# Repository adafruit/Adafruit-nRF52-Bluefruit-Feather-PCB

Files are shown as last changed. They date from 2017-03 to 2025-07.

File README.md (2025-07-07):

# Adafruit-nRF52-Bluefruit-Feather-PCB

PCB files for the Adafruit nRF52 Bluefruit Feather and the Adafruit
nRF52840 Feather Express.

Format is EagleCAD schematic and board layout.

These boards were designed before we spent effort on low power and are not intended for low power usage.

For more details, check out the product page at

    * https://www.adafruit.com/product/3406 (nRF52832)
    * https://www.adafruit.com/product/4062 (nRF52840)

Adafruit invests time and resources providing this open source design,
please support Adafruit and open-source hardware by purchasing
products from Adafruit!

Designed by Adafruit Industries.  
Creative Commons Attribution, Share-Alike license, check license.txt for more information
All text above must be included in any redistribution

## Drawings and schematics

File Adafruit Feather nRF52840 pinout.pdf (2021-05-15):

# Adafruit Feather nRF52840

## https://www.adafruit.com/product/4062

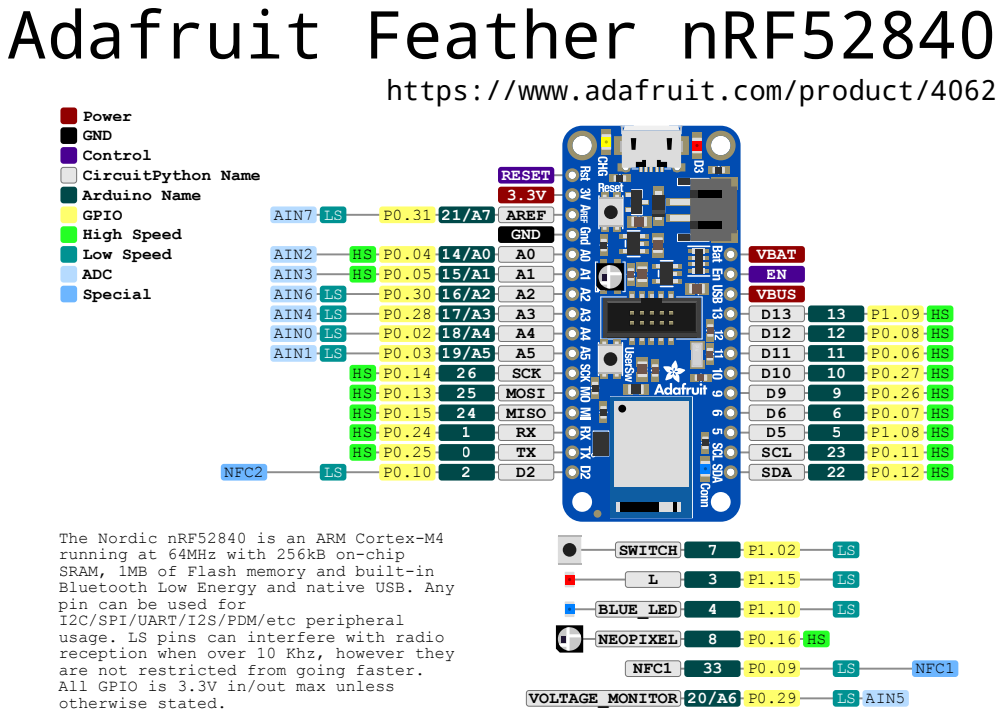
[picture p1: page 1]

The Nordic nRF52840 is an ARM Cortex-M4
running at 64MHz with 256kB on-chip
SRAM, 1MB of Flash memory and built-in
Bluetooth Low Energy and native USB. Any
pin can be used for
I2C/SPI/UART/I2S/PDM/etc peripheral
usage. LS pins can interfere with radio
reception when over 10 Khz, however they
are not restricted from going faster.
All GPIO is 3.3V in/out max unless
otherwise stated.

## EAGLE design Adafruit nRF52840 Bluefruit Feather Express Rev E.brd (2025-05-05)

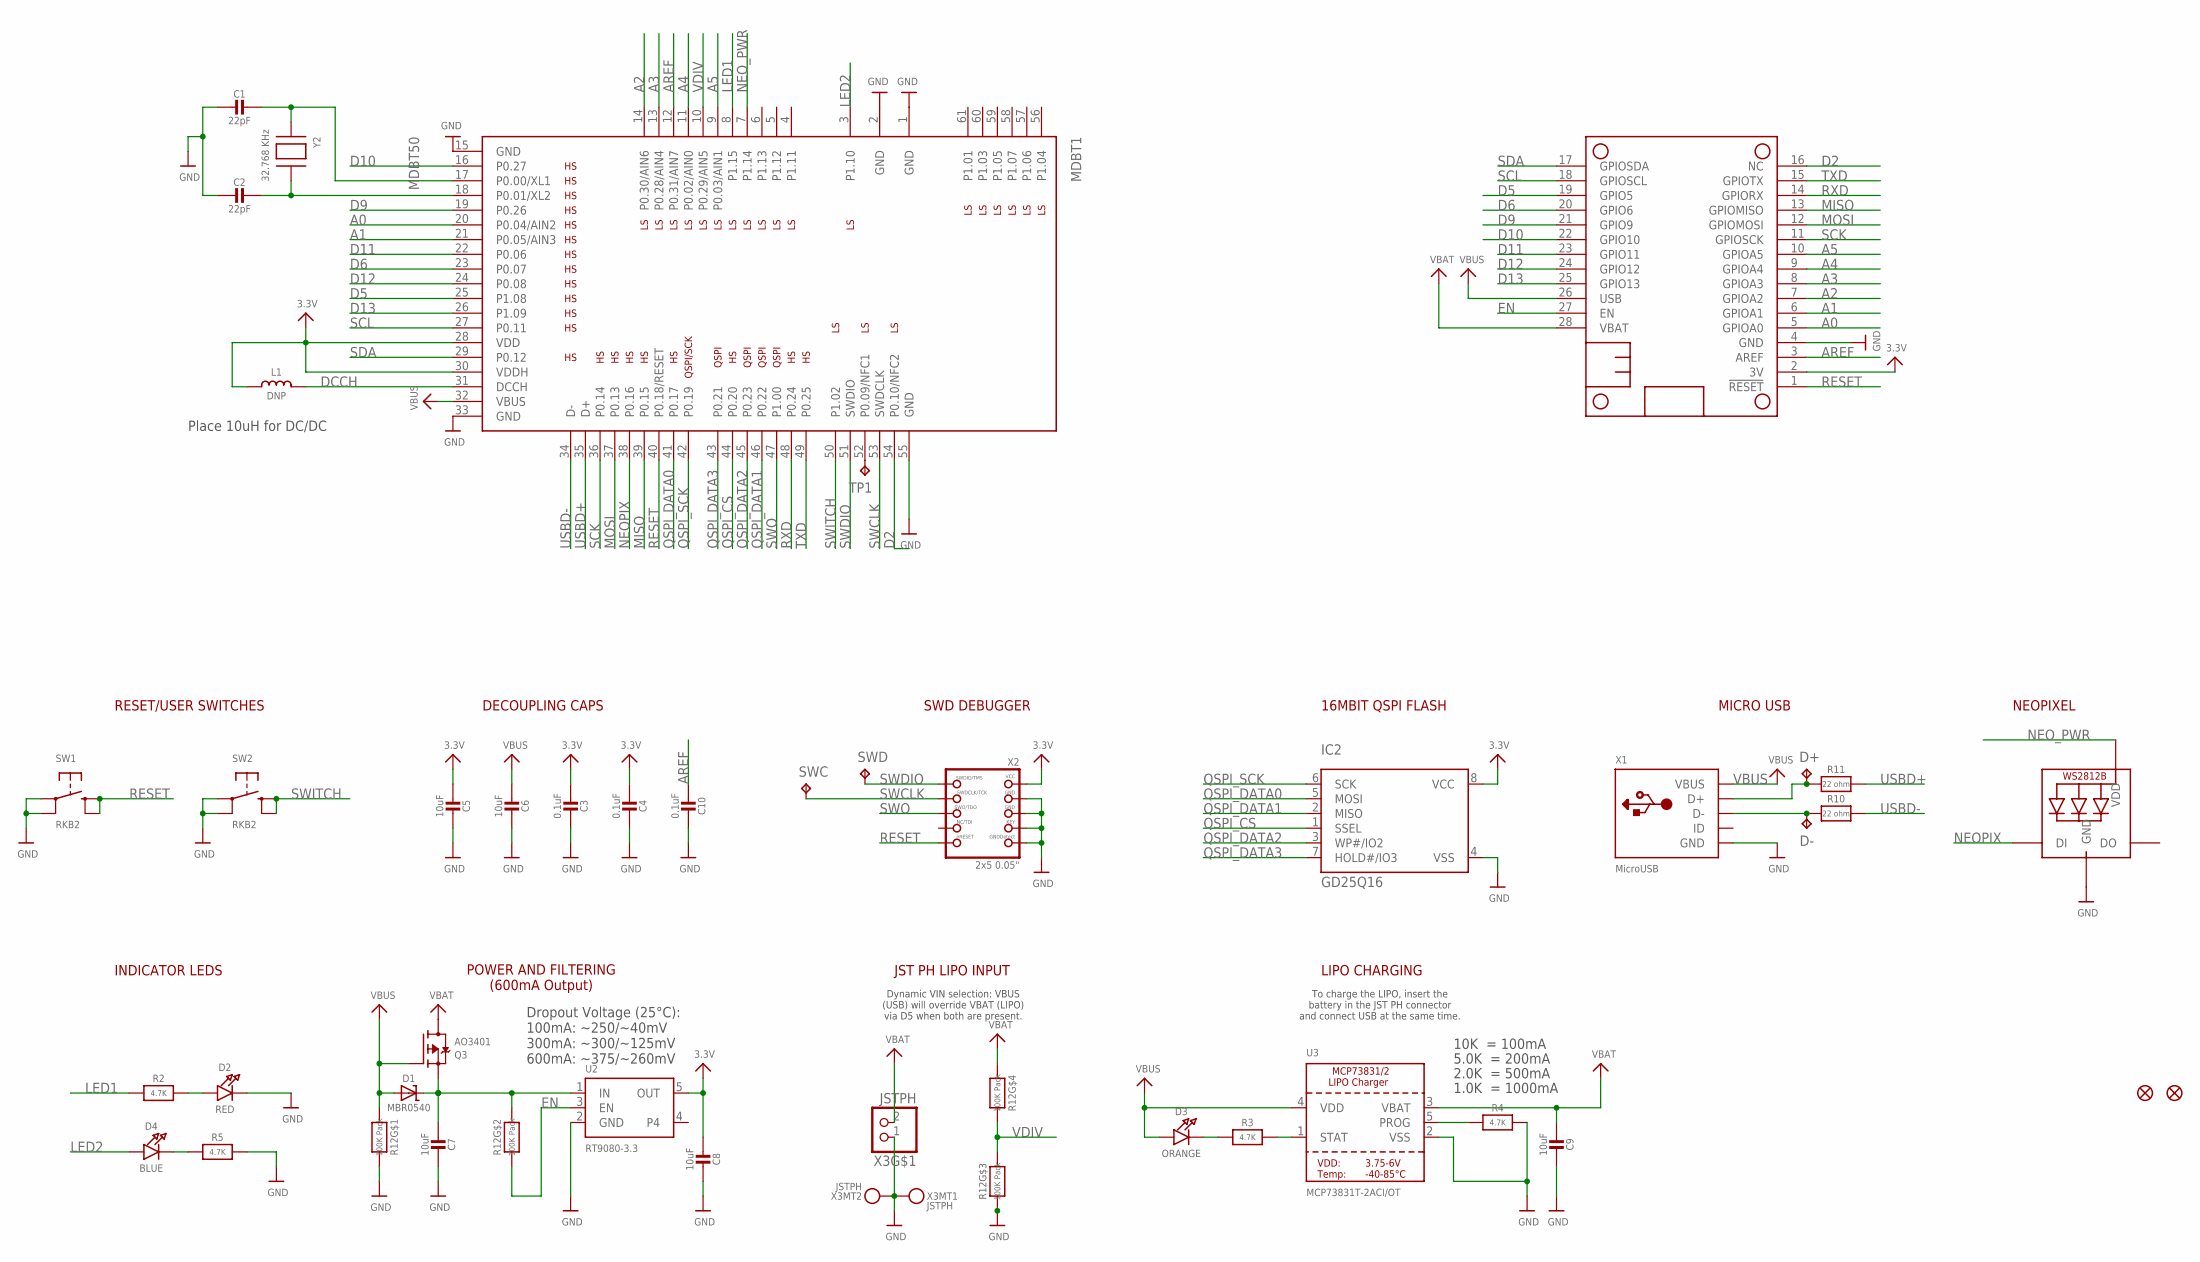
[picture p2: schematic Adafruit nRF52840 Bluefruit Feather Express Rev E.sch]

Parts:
C1, C2: 22pF; 0603-NO
C3, C4, C10: 0.1uF; 0603-NO
C5, C6, C7, C8, C9: 10uF; 0805-NO
D1: MBR0540; SOD-123
D2: RED; CHIPLED_0603_NOOUTLINE
D3: ORANGE; CHIPLED_0603_NOOUTLINE
D4: BLUE; CHIPLED_0603_NOOUTLINE
D+: TPTP10R; TP10R
D-: TPTP10R; TP10R
FID1, FID2: FIDUCIAL_1MM
IC2: GD25Q16; USON8
L1: DNP; _0805MP
LED1: WS2812B_3535FULL; LED3535_FULLPADS
MDBT1: MDBT50
MS1: FEATHERWING_NODIM
Q3: AO3401; SOT23-R
R2, R3, R4, R5: 4.7K; 0603-NO
R10, R11: 22 ohm; _0603MP
R12: 100K Pack; RESPACK_4X0603
SW1, SW2: RKB2; BTN_RKB2_4.6X2.8
SWC: TPTP12R; TP12R
SWD: TPTP12R; TP12R
TP1: TPTP10R; TP10R
U2: RT9080-3.3; SOT23-5; JLC_ROTATION 0
U3: MCP73831T-2ACI/OT; SOT23-5
X1: MicroUSB; 4UCONN_20329_V2
X2: 2x5 0.05"; 2X05_1.27MM_BOX_POSTS
X3: JSTPH; JSTPH2_BATT
Y2: 32.768 KHz; XTAL3215

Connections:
3.3V: C3.2, C4.2, C5.2, C8.2, IC2.8 (VCC), L1.1, MDBT1.28 (VDD), MDBT1.30 (VDDH), MS1.2 (3V), U2.5 (OUT), X2.1 (VCC)
A0: MDBT1.20 (P0.04/AIN2), MS1.5 (GPIOA0)
A1: MDBT1.21 (P0.05/AIN3), MS1.6 (GPIOA1)
A2: MDBT1.14 (P0.30/AIN6), MS1.7 (GPIOA2)
A3: MDBT1.13 (P0.28/AIN4), MS1.8 (GPIOA3)
A4: MDBT1.11 (P0.02/AIN0), MS1.9 (GPIOA4)
A5: MDBT1.9 (P0.03/AIN1), MS1.10 (GPIOA5)
AREF: C10.2, MDBT1.12 (P0.31/AIN7), MS1.3 (AREF)
D2: MDBT1.54 (P0.10/NFC2), MS1.16 (NC)
D5: MDBT1.25 (P1.08), MS1.19 (GPIO5)
D6: MDBT1.23 (P0.07), MS1.20 (GPIO6)
D9: MDBT1.19 (P0.26), MS1.21 (GPIO9)
D10: MDBT1.16 (P0.27), MS1.22 (GPIO10)
D11: MDBT1.22 (P0.06), MS1.23 (GPIO11)
D12: MDBT1.24 (P0.08), MS1.24 (GPIO12)
D13: MDBT1.26 (P1.09), MS1.25 (GPIO13)
D+: D+.TP, R11.1, X1.D+
D-: D-.TP, R10.1, X1.D-
DCCH: L1.2, MDBT1.31 (DCCH)
EN: MS1.27 (EN), R12.2 (1), U2.3 (EN)
GND: C1.2, C2.2, C3.1, C4.1, C5.1, C6.1, C7.1, C8.1, C9.1, C10.1, D2.C, IC2.4 (VSS), LED1.4 (GND), MDBT1.1 (GND), MDBT1.2 (GND), MDBT1.15 (GND), MDBT1.33 (GND), MDBT1.55 (GND), MS1.4 (GND), R4.2, R5.2, R12.3 (1), R12.8 (2), SW1.A, SW1.A' (P1), SW2.A, SW2.A' (P1), U2.2 (GND), U3.2 (VSS), X1.BASE@1 (GND), X1.BASE@2 (GND), X1.GND, X1.SPRT@1 (GND), X1.SPRT@2 (GND), X1.SPRT@3 (GND), X1.SPRT@4 (GND), X2.3 (GND), X2.5 (GND), X2.7 (KEY), X2.9 (GNDDETECT), X3.1, X3.NC1, X3.NC2
LED1: MDBT1.8 (P1.15), R2.1
LED2: D4.A, MDBT1.3 (P1.10)
MISO: MDBT1.39 (P0.15), MS1.13 (GPIOMISO)
MOSI: MDBT1.37 (P0.13), MS1.12 (GPIOMOSI)
unnamed: D3.C, R3.1
unnamed: D2.A, R2.2
unnamed: C1.1, MDBT1.17 (P0.00/XL1), Y2.P$1
unnamed: C2.1, MDBT1.18 (P0.01/XL2), Y2.P$2
unnamed: R3.2, U3.1 (STAT)
unnamed: R4.1, U3.5 (PROG)
unnamed: D4.C, R5.1
NEOPIX: LED1.1 (DI), MDBT1.38 (P0.16)
NEO_PWR: LED1.2 (VDD), MDBT1.7 (P1.14)
NFC2: MDBT1.52 (P0.09/NFC1), TP1.TP
QSPI_CS: IC2.1 (SSEL), MDBT1.44 (P0.20)
QSPI_DATA0: IC2.5 (MOSI), MDBT1.41 (P0.17)
QSPI_DATA1: IC2.2 (MISO), MDBT1.46 (P0.22)
QSPI_DATA2: IC2.3 (WP#/IO2), MDBT1.45 (P0.23)
QSPI_DATA3: IC2.7 (HOLD#/IO3), MDBT1.43 (P0.21)
QSPI_SCK: IC2.6 (SCK), MDBT1.42 (P0.19)
RESET: MDBT1.40 (P0.18/RESET), MS1.1 (!RESET), SW1.B (S), SW1.B' (S1), X2.10 (NRESET)
RXD: MDBT1.48 (P0.24), MS1.14 (GPIORX)
SCK: MDBT1.36 (P0.14), MS1.11 (GPIOSCK)
SCL: MDBT1.27 (P0.11), MS1.18 (GPIOSCL)
SDA: MDBT1.29 (P0.12), MS1.17 (GPIOSDA)
SWCLK: MDBT1.53 (SWDCLK), SWC.TP, X2.4 (SWDCLK)
SWDIO: MDBT1.51 (SWDIO), SWD.TP, X2.2 (SWDIO)
SWITCH: MDBT1.50 (P1.02), SW2.B (S), SW2.B' (S1)
SWO: MDBT1.47 (P1.00), X2.6 (SWO)
TXD: MDBT1.49 (P0.25), MS1.15 (GPIOTX)
USBD+: MDBT1.35 (D+), R11.2
USBD-: MDBT1.34 (D-), R10.2
VBAT: C9.2, MS1.28 (VBAT), Q3.3 (D), R12.4 (1), U3.3 (VBAT), X3.2
VBUS: C6.2, D1.A, D3.A, MDBT1.32 (VBUS), MS1.26 (USB), Q3.1 (G), R12.1, U3.4 (VDD), X1.VBUS
VDIV: MDBT1.10 (P0.29/AIN5), R12.5 (2), R12.6 (2)
VHI: C7.2, D1.C, Q3.2 (S), R12.7 (2), U2.1 (IN)

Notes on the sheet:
10K = 100mA
5.0K = 200mA
2.0K = 500mA
1.0K = 1000mA
LIPO CHARGING
To charge the LIPO, insert the battery in the JST PH connector and connect USB at the same time.
POWER AND FILTERING (600mA Output)
JST PH LIPO INPUT
Dynamic VIN selection: VBUS (USB) will override VBAT (LIPO) via D5 when both are present.
Dropout Voltage (25°C): 100mA: ~250/~40mV 300mA: ~300/~125mV 600mA: ~375/~260mV
INDICATOR LEDS
RESET/USER SWITCHES
DECOUPLING CAPS
SWD DEBUGGER
16MBIT QSPI FLASH
MICRO USB
NEOPIXEL
Place 10uH for DC/DC

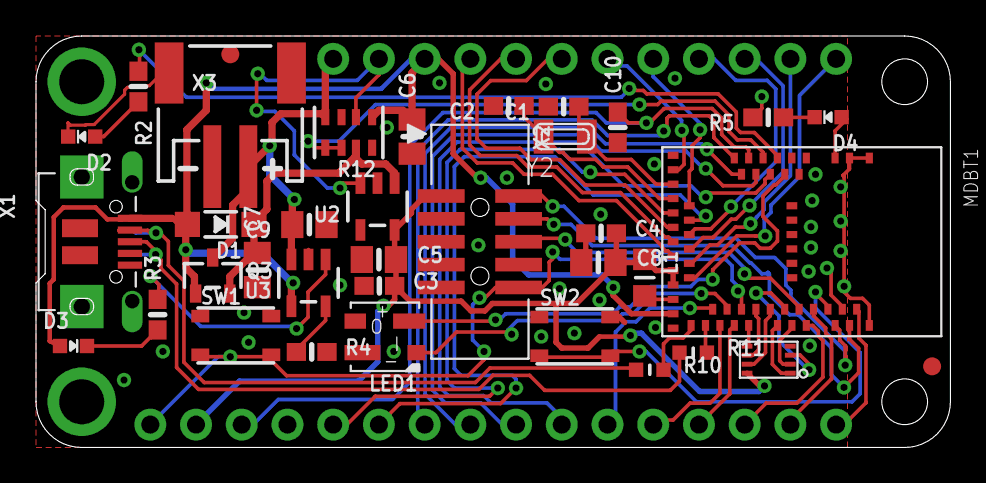
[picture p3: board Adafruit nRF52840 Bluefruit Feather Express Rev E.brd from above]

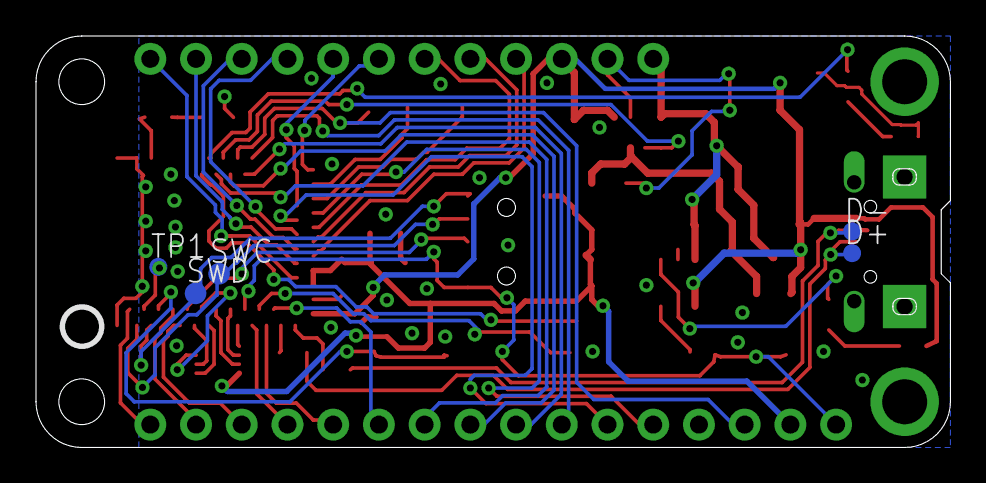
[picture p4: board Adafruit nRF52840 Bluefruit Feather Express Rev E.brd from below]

Board: 2 copper layers, 50.8 x 22.9 mm, 45 parts (7 on the bottom side), 57 nets.

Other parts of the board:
U$10: PCBFEAT-REV-056
U$12: NRF52840_BOT
U$14: NRF52840_TOP

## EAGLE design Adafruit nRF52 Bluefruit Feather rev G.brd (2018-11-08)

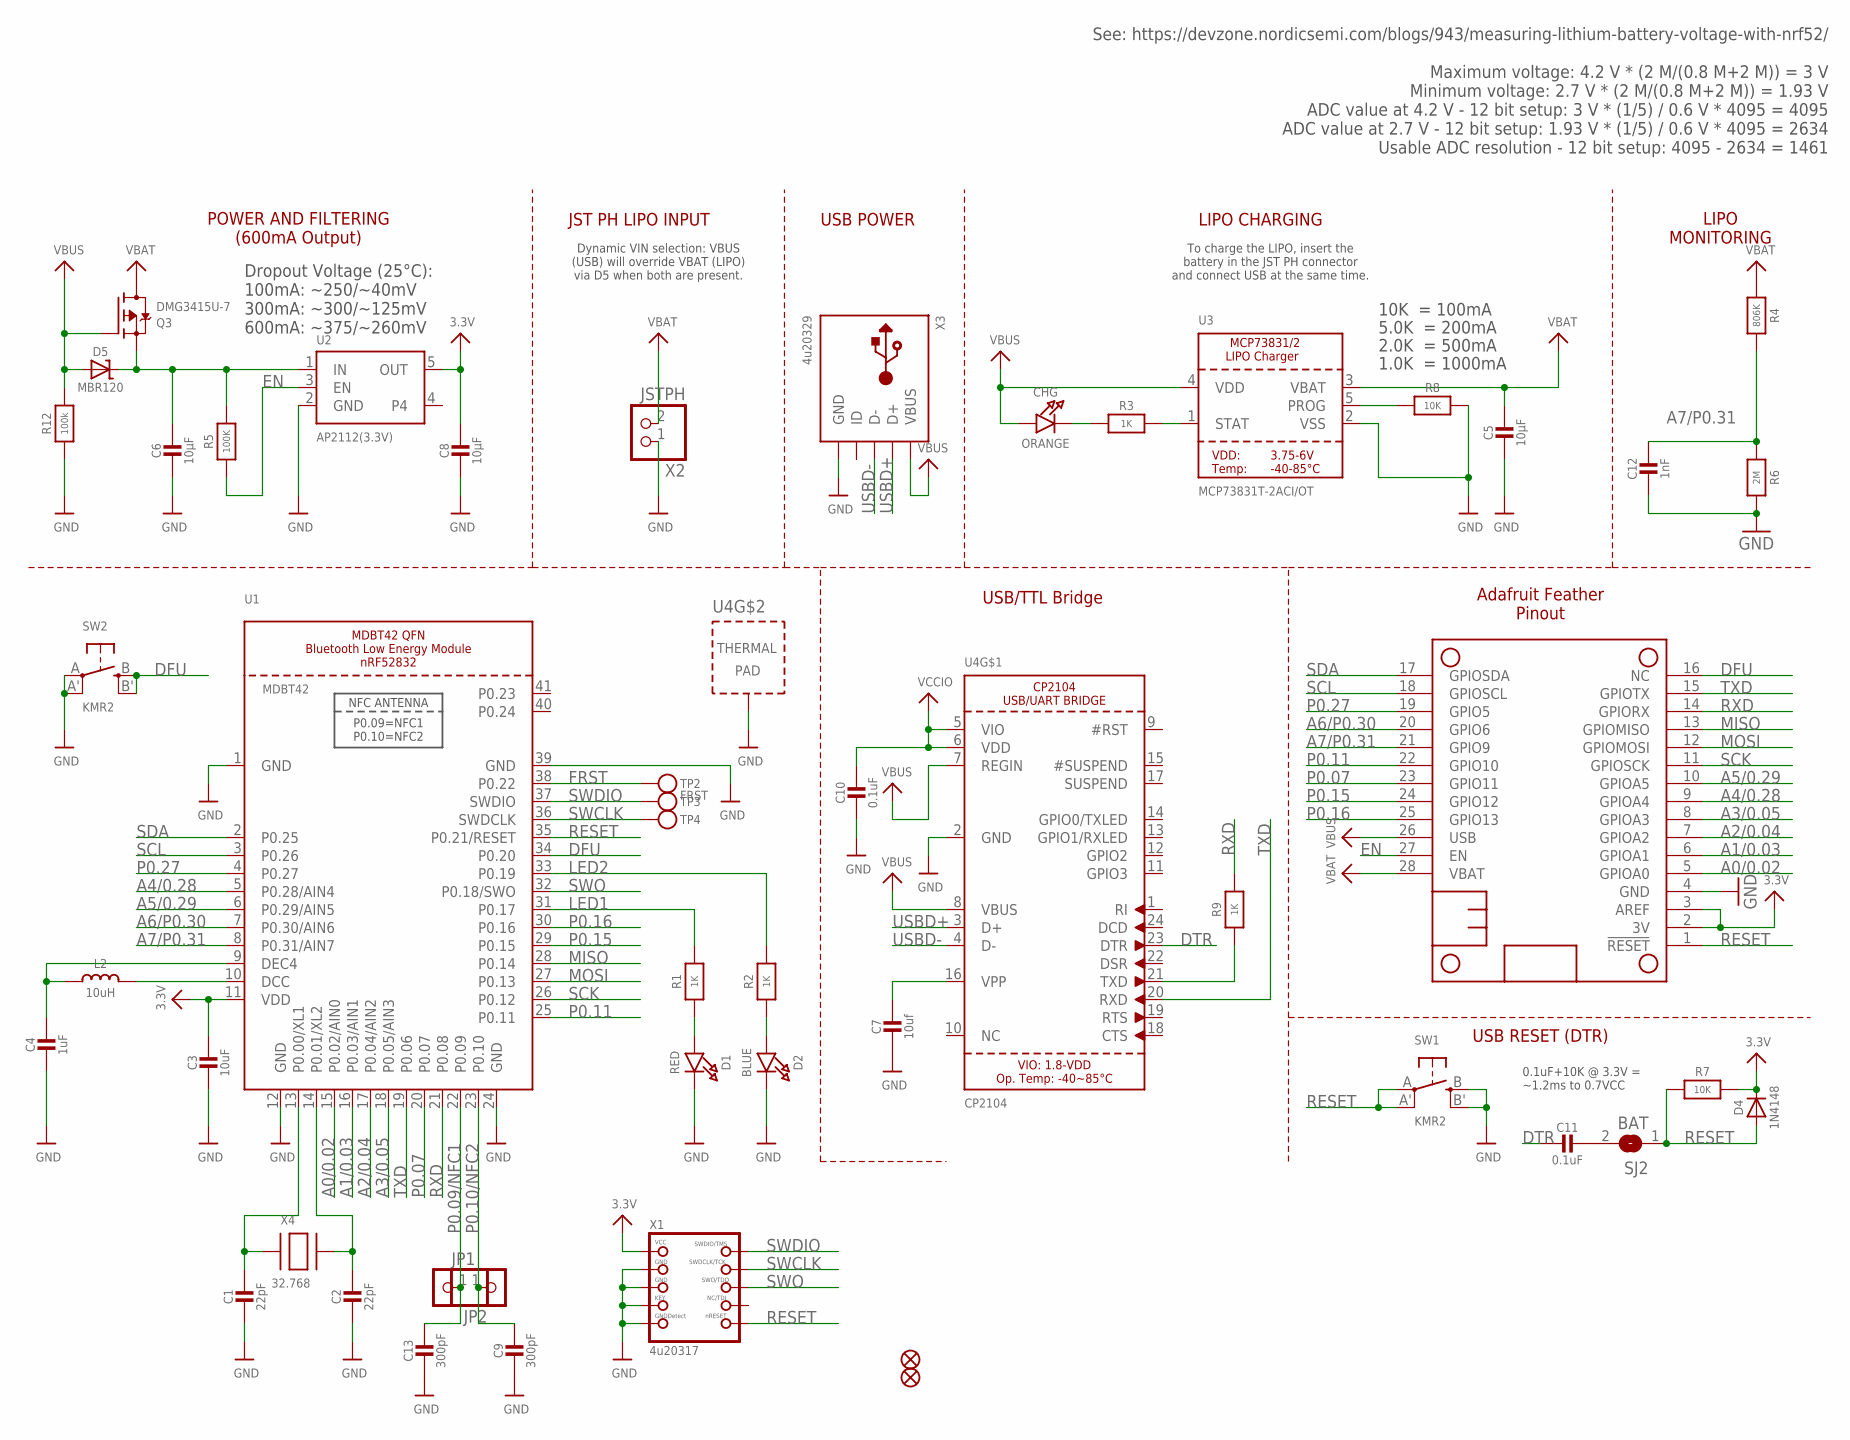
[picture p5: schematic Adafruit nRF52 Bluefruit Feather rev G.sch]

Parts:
C1, C2: 22pF; 0603-NO
C3: 10uF; 0805-NO
C4: 1uF; 0603-NO
C5, C6, C8: 10µF; 0805-NO
C7: 10uf; 0805-NO
C9, C13: 300pF; _0603MP
C10, C11: 0.1uF; 0603-NO
C12: 1nF; 0603-NO
CHG: ORANGE; CHIPLED_0805_NOOUTLINE
D1: RED; CHIPLED_0805_NOOUTLINE
D2: BLUE; CHIPLED_0805_NOOUTLINE
D4: 1N4148; SOD-323
D5: MBR120; SOD-123
FID1, FID3: FIDUCIAL_1MM
JP1, JP2: HEADER-1X12MM; 1X01_2MM
L2: 10uH; 0805-NO
MS1: FEATHERWING_NODIM
Q3: DMG3415U-7; SOT23-R
R1, R2, R3, R9: 1K; 0603-NO
R4: 806K; 0603-NO
R5: 100K; 0603-NO
R6: 2M; 0603-NO
R7, R8: 10K; 0603-NO
R12: 100k; 0603-NO
SJ2: BAT; SOLDERJUMPER_CLOSEDWIRE
SW1, SW2: KMR2; BTN_KMR2_4.6X2.8
TP2: FRST; PAD-1.5X2.0
TP3, TP4: TESTPOINTROUND2MM; TESTPOINT_ROUND_2MM
U1: MDBT42; BLE_MODULE_RAYTAC_MDBT42
U2: AP2112(3.3V); SOT23-5
U3: MCP73831T-2ACI/OT; SOT23-5
U4: CP2104; QFN24_4MM_SMSC
X1: 4u20317; 2X05_1.27MM_BOX_POSTS
X2: JSTPH; JSTPH2
X3: 4u20329; 4UCONN_20329_V2
X4: 32.768; XTAL3215

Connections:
3.3V: C3.1, C8.1, D4.C, MS1.2 (3V), MS1.3 (AREF), R7.2, U1.11 (VDD), U2.5 (OUT), X1.1 (VCC)
A0/0.02: MS1.5 (GPIOA0), U1.15 (P0.02/AIN0)
A1/0.03: MS1.6 (GPIOA1), U1.16 (P0.03/AIN1)
A2/0.04: MS1.7 (GPIOA2), U1.17 (P0.04/AIN2)
A3/0.05: MS1.8 (GPIOA3), U1.18 (P0.05/AIN3)
A4/0.28: MS1.9 (GPIOA4), U1.5 (P0.28/AIN4)
A5/0.29: MS1.10 (GPIOA5), U1.6 (P0.29/AIN5)
A6/P0.30: MS1.20 (GPIO6), U1.7 (P0.30/AIN6)
A7/P0.31: C12.1, MS1.21 (GPIO9), R4.2, R6.1, U1.8 (P0.31/AIN7)
DFU: MS1.16 (NC), SW2.B (S), SW2.B' (S1), U1.34 (P0.20)
DTR: C11.2, U4.23 (DTR)
EN: MS1.27 (EN), R5.1, U2.3 (EN)
FRST: TP2.P$1, U1.38 (P0.22)
GND: C1.2, C2.2, C3.2, C4.2, C5.2, C6.2, C7.2, C8.2, C9.2, C10.2, C12.2, C13.2, D1.C, D2.C, MS1.4 (GND), R6.2, R8.2, R12.1, SW1.B (S), SW1.B' (S1), SW2.A, SW2.A' (P1), U1.1 (GND), U1.12 (GND), U1.24 (GND), U1.39 (GND), U2.2 (GND), U3.2 (VSS), U4.2 (GND), U4.THERM (TP), X1.3 (GND), X1.5 (GND), X1.7 (KEY), X1.9 (GNDDETECT), X2.1, X3.BASE@1 (GND), X3.BASE@2 (GND), X3.GND, X3.SPRT@1 (GND), X3.SPRT@2 (GND), X3.SPRT@3 (GND), X3.SPRT@4 (GND)
LED1: R1.2, U1.31 (P0.17)
LED2: R2.2, U1.33 (P0.19)
MISO: MS1.13 (GPIOMISO), U1.28 (P0.14)
MOSI: MS1.12 (GPIOMOSI), U1.27 (P0.13)
unnamed: C1.1, U1.13 (P0.00/XL1), X4.P$1
unnamed: C2.1, U1.14 (P0.01/XL2), X4.P$2
unnamed: L2.2, U1.10 (DCC)
unnamed: CHG.C, R3.1
unnamed: D1.A, R1.1
unnamed: D2.A, R2.1
unnamed: C4.1, L2.1, U1.9 (DEC4)
unnamed: R3.2, U3.1 (STAT)
unnamed: R8.1, U3.5 (PROG)
unnamed: R9.1, U4.21 (TXD)
unnamed: C11.1, SJ2.2
unnamed: C7.1, U4.16 (VPP)
P0.07: MS1.23 (GPIO11), U1.20 (P0.07)
P0.09/NFC1: C13.1, JP2.1, U1.22 (P0.09)
P0.10/NFC2: C9.1, JP1.1, U1.23 (P0.10)
P0.11: MS1.22 (GPIO10), U1.25 (P0.11)
P0.15: MS1.24 (GPIO12), U1.29 (P0.15)
P0.16: MS1.25 (GPIO13), U1.30 (P0.16)
P0.27: MS1.19 (GPIO5), U1.4 (P0.27)
RESET: D4.A, MS1.1 (!RESET), R7.1, SJ2.1, SW1.A, SW1.A' (P1), U1.35 (P0.21/RESET), X1.10 (NRESET)
RXD: MS1.14 (GPIORX), R9.2, U1.21 (P0.08)
SCK: MS1.11 (GPIOSCK), U1.26 (P0.12)
SCL: MS1.18 (GPIOSCL), U1.3 (P0.26)
SDA: MS1.17 (GPIOSDA), U1.2 (P0.25)
SWCLK: TP4.P$1, U1.36 (SWDCLK), X1.4 (SWDCLK)
SWDIO: TP3.P$1, U1.37 (SWDIO), X1.2 (SWDIO)
SWO: U1.32 (P0.18/SWO), X1.6 (SWO)
TXD: MS1.15 (GPIOTX), U1.19 (P0.06), U4.20 (RXD)
USBD+: U4.3 (D+), X3.D+
USBD-: U4.4 (D-), X3.D-
VBAT: C5.1, MS1.28 (VBAT), Q3.3 (D), R4.1, U3.3 (VBAT), X2.2
VBUS: CHG.A, D5.A, MS1.26 (USB), Q3.1 (G), R12.2, U3.4 (VDD), U4.7 (REGIN), U4.8 (VBUS), X3.VBUS
VCCIO: C10.1, U4.5 (VIO), U4.6 (VDD)
VIN: C6.1, D5.C, Q3.2 (S), R5.2, U2.1 (IN)

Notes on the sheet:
10K = 100mA
5.0K = 200mA
2.0K = 500mA
1.0K = 1000mA
LIPO CHARGING
LIPO MONITORING
To charge the LIPO, insert the battery in the JST PH connector and connect USB at the same time.
POWER AND FILTERING (600mA Output)
JST PH LIPO INPUT
Dynamic VIN selection: VBUS (USB) will override VBAT (LIPO) via D5 when both are present.
Dropout Voltage (25°C): 100mA: ~250/~40mV 300mA: ~300/~125mV 600mA: ~375/~260mV
USB POWER
USB/TTL Bridge
Adafruit Feather Pinout
See: https://devzone.nordicsemi.com/blogs/943/measuring-lithium-battery-voltage-with-nrf52/ Maximum voltage: 4.2 V * (2 M/(0.8 M+2 M)) = 3 V Minimum voltage: 2.7 V * (2 M/(0.8 M+2 M)) = 1.93 V ADC value at 4.2 V - 12 bit setup: 3 V * (1/5) / 0.6 V * 4095 = 4095 ADC value at 2.7 V - 12 bit setup: 1.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
USB RESET (DTR)
0.1uF+10K @ 3.3V = ~1.2ms to 0.7VCC

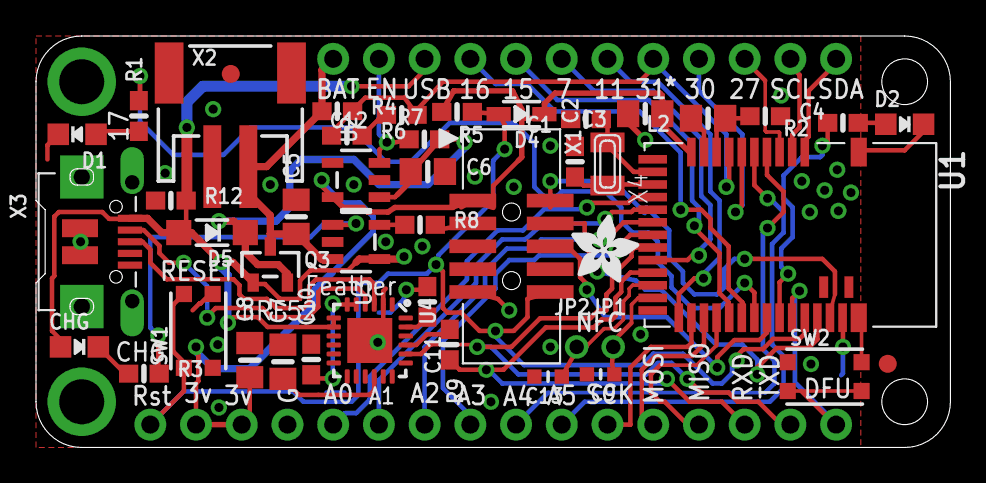
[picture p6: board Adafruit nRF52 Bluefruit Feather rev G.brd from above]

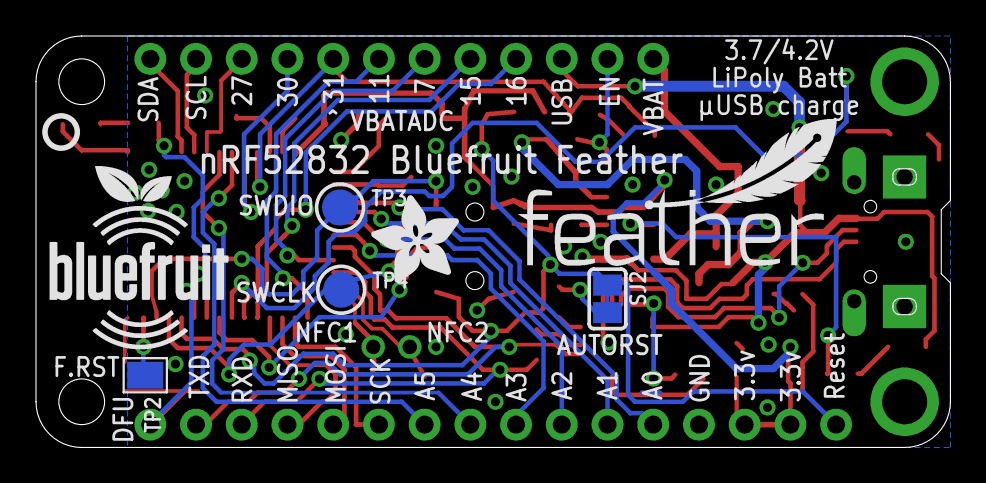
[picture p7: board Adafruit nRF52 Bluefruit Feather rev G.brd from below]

Board: 2 copper layers, 50.8 x 22.9 mm, 54 parts (8 on the bottom side), 52 nets.

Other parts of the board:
U$17: PCBFEAT-REV-040
U$45: BLUEFRUITLOGO_100MM
U$46: FEATHERLOGO_MED
U$47: ADAFRUIT_5MM
U$49: ADAFRUIT_3.5MM

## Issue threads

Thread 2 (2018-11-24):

No space for screw heads on one side

jps2000, 2018-11-24:
There is almost no space for screws on the MDBT42 side. in particular the LED is endangered.
Pls improve  in the next layout if possible. Find attached my suggestions.
[adafruit feather nrf52 revG_JPS.zip](https://github.com/adafruit/Adafruit-nRF52-Bluefruit-Feather-PCB/files/2612101/adafruit.feather.nrf52.revG_JPS.zip)

ladyada, 2018-11-25:
thanks for the note! these are already in production, and we're unlikely to do any revisions soon - but when we do we'll move the LED as well :)

jps2000, 2018-11-26:
Thanks.
Of course I understand that.
Lets follow the basic wisdom "never change a running system"

ladyada, 2018-11-26:
indeed :)

Closed 2018-11-25.

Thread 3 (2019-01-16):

nRF52840 question: why is the AP2112 present on the board?

lbdroid, 2019-01-16:
The specifications for the nRF52840 include DCDC and LDO power regulators onboard capable of being supplied by any voltage from 1.7 to 5.5, including the ability to drive external 3.3v components (specifically, the multi-color LED and the external flash). The AP2112 has a quiescent current of 55-80 uA, which appears to be an unnecessary waste since the datasheet for the nRF52840 suggest that it can consume as little as 1 uA while being supplied by 5V.

It seems to me that the circuit would be simplified and efficiency improved by removing the AP2112, and instead of tying the nRF52840's VDDH to VDD, connect VDDH to the cathode of D1.

ladyada, 2019-01-16:
we need 300mA minimum for accessories, whats the spec of the nRF52840 LDO?

lbdroid, 2019-01-16:
Ah, ok. Then it makes sense since the nRF is maximum 25 mA. I suppose then that it would be nice to be able to operate without the AP2112 when external accessories are not required.

Closed 2019-01-16.

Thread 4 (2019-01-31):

Low power consumption on nrf52840

jps2000, 2019-01-31:
Just looked over the schematic of rev D
To achieve lowest Vbat and OFF current pls consider following changes:

1) Make the VDIV divider same as in the nrf52832 board (high ohmic  + add capacitor!)
It takes now 20uA

2)EN Pullup use 1M or even more to  allow low power shutdown
 (EN pulldown is 3M , >1.5V is required
It takes  now 40 uA

3)  Replace D1 MBR120 by a  Si diode which has less leakage current
It takes now 25uA to 200uA
Thanks

ladyada, 2019-01-31:
awesome, thanks!
1. please try the vdiv with higher values, let us know if they work!
2. please try various pullup values, we found 100k works best
3. please recommend a same-package diode with 0.2V forward voltage and low leakage

jps2000, 2019-02-05:
ad 1.
The vdiv with higher values is indeed present in the 52832 board. however such  high impedance voltage dividers need capacitor to gnd for proper adc operation ( done in the 52832 board)
--> suggest to add capacitor 1..10nF  in next  52840 layout and change voltage divider to 2M + 2M.
ad 2.
2M2 also works fine. The penalty is that inadvertently touching the pins with fingers can lead to  a short shut down.  So this may be a problem  with modules lying around on the table. 220k or 470k may be a compromise.
ad 3.
I see no need for a 0.2V voltage drop as  the diode just supplies the 3V3 low drop voltage regulator.
So I actually use just a 1N4148 instead of the Schottky. However current consumption is then limited to 150mA. It is likely less robust to shorts.
There are also some more capable SOD123  Si diodes but they are somehow rare.

With above changes I  achieved <10uA  (~7uA) off current (with EN = LOW).
Maybe helpful for some users.

jps2000, 2019-02-05:
There are these SL1 A... M types from Diotec for example they claim <1uA@ 25° leakage
may be considered.....

jps2000, 2019-04-04:
seems to be actual
https://forums.adafruit.com/posting.php?mode=reply&f=57&t=146360

Eric-FR, 2020-04-21:
(2): I made a current measurement on my Feather nrf52840 with an external power supply of 3.6 V on the BAT pin. I found 100 µA and I don't understand (although not critical for my project). 100 kOhm on the ENable pin: 36 µA. Battery voltage divider, 200 kOhm: 18 µA.

(4): There is a neopixel LED, ref.: WS2812B. The Quiescent Current is of 0,5 mA when the LED is off.

[https://lowpowerlab.com/forum/general-topics/ws2812b-rgb-led-measurements/](url).

This should explain why I get a current of 600 µA at rest with a loopless sketch.

[https://github.com/MacGyverNL/Adafruit_nRF52_Arduino/tree/LowPower_examples/libraries/Bluefruit52Lib/examples/LowPower/Blink_loopless](url)

One should note that on the ItsyBitsy, there is DotStar LED with ref. APA102-2020. It is also having a gargantuan Quiescent Current of 0,8 mA.

[https://memcpy.io/apa102-led-current-usage.html](url)

The latter may be easier to unsolder, considering the SWD connector position on the Feather one. But, overall, it seems to be a big drawback to low power management of booth boards. Again, the Feather nfr52832 would be more suitable.

mhx, 2020-04-29:
FWIW, I can confirm that...
- ripping out the neopixel
- replacing the AP2112 with an AP7354D
- replacing the MBR120 with an STTH1R02ZF
...brings the total current draw down to 20µA. 18µA are still wasted for the VDIV (no need to verify that and I'm not particularly keen on replacing the 4x100k array), the remainder is likely 1.5µA for the Raytac module and 0.5µA reverse leakage from the STTH1R02ZF.

mhx, 2020-04-29:
> true it does not need to be a schottky since, but we need to supply up to 500mA peak to the regulator, can you suggest a diode that can do that? (in the same package)

The STTH1R02ZF can handle up to 1A with a max. 0.5µA reverse leakage.
The AP7354D seems to be fully compatible with the AP2112.

ladyada, 2020-04-29:
@mhx thank you for being so helpful :) we'll check those parts out!

ladyada, 2020-04-29:
@mhx  STTH1R02ZF has very high Vf, 0.75 - can you try MBR054?
https://www.digikey.com/product-detail/en/on-semiconductor/MBR0540T1G/MBR0540T1GOSTR-ND/918576

mhx, 2020-04-29:
WRT the voltage divider, there's a [full article from Nordic Semi](https://devzone.nordicsemi.com/nordic/nordic-blog/b/blog/posts/measuring-lithium-battery-voltage-with-nrf52) on how to design a high resistance divider for the nRF52. It's really straightforward and the only additional component needed is a capacitor as already mentioned by @jps2000.

mhx, 2020-04-29:
> @mhx STTH1R02ZF has very high Vf, 0.75 - can you try MBR054?
> https://www.digikey.com/product-detail/en/on-semiconductor/MBR0540T1G/MBR0540T1GOSTR-ND/918576
I don't have one of those lying around, but I can put a handful on my next digikey order and give it a try.
Why are you concerned about the higher voltage drop? There should be plenty of headroom going from 5 to 3.3V.

ladyada, 2020-04-29:
USB can droop down to 4.25V when current spikes - at 1A Vf 0.9V and we also need some headroom for the LDO at spikes

mhx, 2020-04-29:
> The AP7354D seems to be fully compatible with the AP2112.
Actually, it's not — just had another look at the datasheet — it'll only output up to 150mA. :/

glenne, 2021-02-07:
I see this thread is over a year old.  Any chance an updated rev of the nrf52840 will have the lower current mods?

glenne, 2021-02-20:
@ladyada [I tried the mods](https://forums.adafruit.com/viewtopic.php?f=57&t=164751#p855542) with the AP7354D and MBR0501T1G and got down to 29 uA.  150mA is plenty for my application.  Would really be nice if the production board didn't need hardware mods to be a 'low energy' BLE peripheral.

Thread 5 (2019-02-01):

Schematic for nrf52840 (on website) has an typo/error

jpconstantineau, 2019-02-01:
Comment on dynamic VIN selection pints to D5.  I think you mean D1.

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

awneil, 2020-11-12:
indeed - there is no D5.

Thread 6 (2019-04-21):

No polarity indicated for battery connector on silkscreen

dsiee, 2019-04-21:
A small + indicating battery polarity would be beneficial on the silkscreen. There is room for this on the back either side of the voltage indication "3.7/4.2V". Particularly important with the now large supply of PH2.0 connector batteries used in mini-quads with the opposite polarity coupled with the minimal reverse polarity handling of the board.

int3ll3ct, 2019-11-09:
I concur, I just smoked a board, a 5-pin component melted on the board, I incorrectly asumed that the battery industry was standardizing around this style plug AND polarity...

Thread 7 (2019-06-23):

Neopixel problems when USB is above 5V (nrf52840)

dsteinman, 2019-06-23:
Although a computer USB connection is usually around 5.0V, some USB chargers put out slightly more than that.  I have 3 on hand at 5.11V, 5.15V, and 5.26V.  All three create problems which in my case, manifest as the first Neopixel on a WS2812 strip flickering green (I am using the Adafruit neopixel library).

The 5.15V one (an iPad Charger) works best of the three, the neopixel still occasionally flickers green, but quite a lot less.  The other chargers are a Samsung phone charger, and a charger that came with a Raspberry Pi 3.

The problems persist regardless of whether the battery is connected.

I noticed in the schematic, that the VBUS line is wired to the nrf pin 32.  I'd need to look into the NRF documentation a bit further to determine what the threshold is for this pin, but I suspect that it may be the cause of my problems.

Would wiring the VHI line to pin 32 be a potential fix?  It's after the D1 diode, so the voltage would be a tad lower, and may resolve the issue.  (I'm probably going to try this out and see the results).

ladyada, 2019-06-23:
hiya you probably need a level shifter - see https://learn.adafruit.com/adafruit-neopixel-uberguide/

dsteinman, 2019-06-23:
I should have clarified, I am not using the 5V line to power the neopixels.  It is a 24 pixel strip connected to the 3.3V line from the feather board.  So it's already at 3.3V (althought it tests slightly lower ~3.26V).  Everything works good until a USB charger sends >5V.

ladyada, 2019-06-23:
hiya we'd need to see some scope traces of the power/data to see whats going on

Closed 2019-06-23.

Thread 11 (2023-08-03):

Please provide PDF files of schematic and gerbers of layout

smahnken, 2023-08-03:
Please post PDF files of the schematic and gerber files for the board layout so that we can see the design without having to install Eagle.

Thank you.

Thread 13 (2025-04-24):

Higher power consumption on nrf52840 Rev E boards

donmsmall, 2025-04-24:
Recent [nrf52840](https://www.adafruit.com/product/4062) boards I've bought are now showing an updated PCB version E.  I have not been able to find any documentation concerning changes from Rev D to Rev E. Last revision history on the product page is dated Nov. 2019.   The nrf52840 learning guide contains a reference to [NEOPIXEL_POWER](https://learn.adafruit.com/introducing-the-adafruit-nrf52840-feather?view=all#circuitpython-pins-and-modules) in the CircuitPython section.  I've also found a reference in the Arduino variant.cpp file to a NEO Pixel power pin.  Sounds promissing that we might not need to remove the NEO Pixel LED from the board to get lowerr current.

variant.h

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

variant.cpp

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

I've been using the Rev D board and removing the NEO Pixel LED to get an idle current of 63uA, which is great for my project.

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

But now the Rev E board with NEO Pixel still on the board shows idle current of 1.1mA.

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

Do I have the logic backwards to disable the NEO Pixel?  I wrote some test code to prove to myself that setting PIN_NEOPIXEL_POWER high does enable the NEO Pixel and setting PIN_NEOPIXEL_POWER low turns it off.  I've removed the NEO Pixel LED on one board and still get 1.1mA of idle current.

I've not been able to find a schematic for Rev E, so no idea how to get the current down similar to the discussion in [Issue #4 ](https://github.com/adafruit/Adafruit-nRF52-Bluefruit-Feather-PCB/issues/4).

Rev E with no mods is 1.1mA and Rev D with no mods is around .5mA.

Any help on power reduction would be appreciated.  Links to schematics would be helpful but I understand how those are probably just copied and your designs stolen so now you have to keep those under lock and key.

ladyada, 2025-05-02:
yes these boards were designed before we spent effort on low power (they were never intended for low power usage :/
@BlitzCityDIY plz post the rev E files at your convenience

BlitzCityDIY, 2025-05-05:
rev E files have been posted

arunshivaram, 2025-06-15:
I recently got a rev E board and was doing power measurements with PPK2 and came across this issue. I was able to get to ~35 μA by just pulling the NEOPIXEL_POWER pin low. Documented the code snippet used and the PPK2 screenshots here in case it is helpful

https://github.com/arunshivaram/microcontroller_power_profiles/tree/main/Adafruit_nRF52840_Feather_Express

ladyada, 2025-07-04:
@BlitzCityDIY you can update the dox then close

BlitzCityDIY, 2025-07-07:
docs are updated

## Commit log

2019-01-02 Added nRF52840 Feather Express
    [Adafruit Feather nRF52840 Rev .sch, Adafruit Feather nRF52840 Rev D.brd]
2019-01-02 File rename
    [Adafruit nRF52840 Bluefruit Feather Express Rev D.brd, Adafruit nRF52840 Bluefruit Feather Express Rev D.sch]
2021-05-15 Add pin reference PDF
2025-05-05 adding nrf52840 feather rev E
    [Adafruit nRF52840 Bluefruit Feather Express Rev E.brd, Adafruit nRF52840 Bluefruit Feather Express Rev E.sch]

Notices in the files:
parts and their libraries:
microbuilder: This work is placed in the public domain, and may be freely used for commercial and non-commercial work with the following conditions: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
